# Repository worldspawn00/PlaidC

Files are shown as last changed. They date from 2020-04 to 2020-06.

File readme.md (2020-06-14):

# Plaid type C

Plaid C

Redesign of the Plaid PCB to use USBC and 2u stabilized layouts

Assembly and BOM generally follows the standard Plaid with the exception of the USBC port (USB4085-GF-A GCT) and 2 additional 5.1k resistors for C to C identification.  The PCB can also now take PCB-mount 2u stabilizers for the 2u spacebar locations, clip in or screw in will work.

https://github.com/hsgw/plaid/blob/master/doc/en/soldering.md

* Keyboard Maintainer: [Worldspawn00](https://github.com/Worldspawn00)

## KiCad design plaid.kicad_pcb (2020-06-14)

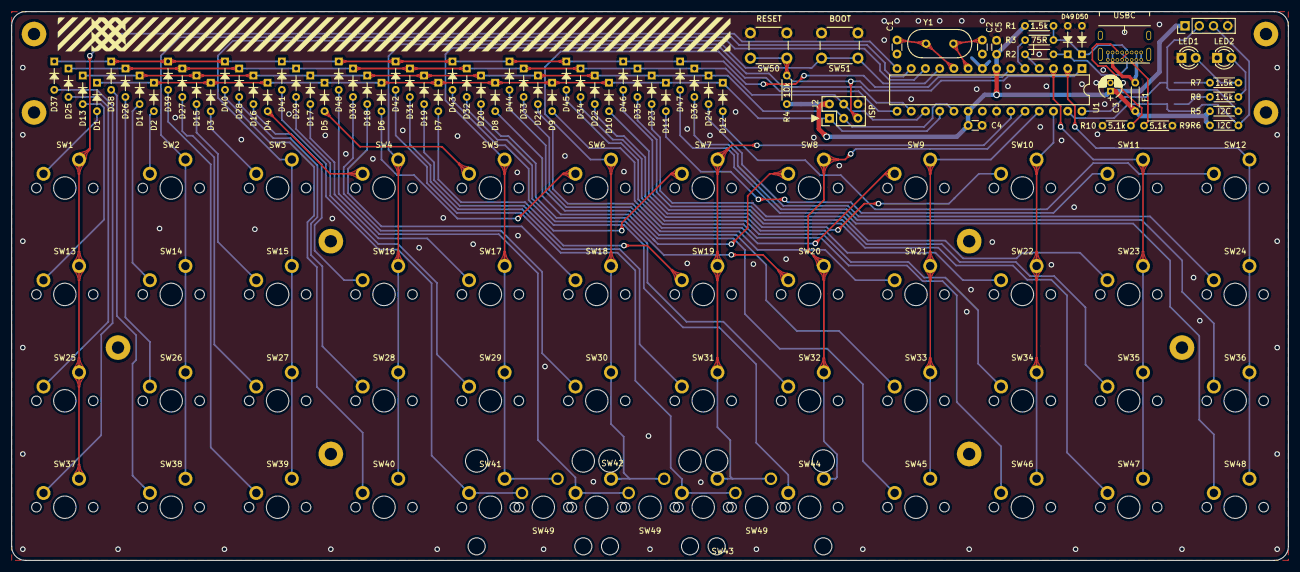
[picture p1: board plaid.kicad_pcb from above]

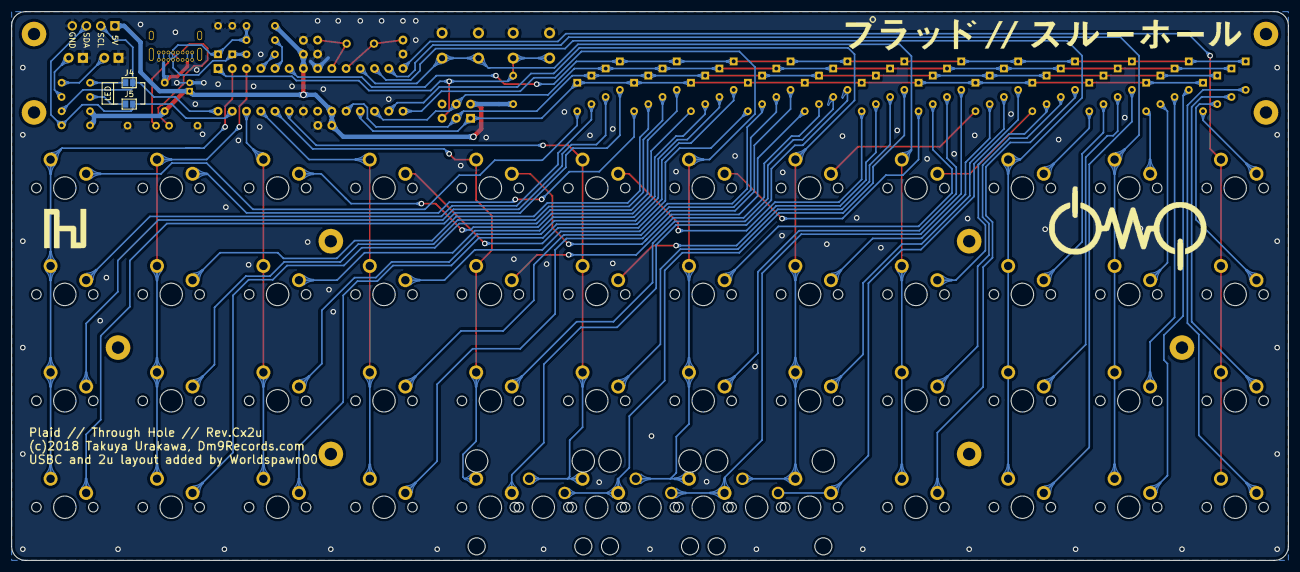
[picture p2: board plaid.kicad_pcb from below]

Board: 2 copper layers, 228.0 x 98.0 mm, 138 parts (2 on the bottom side), 80 nets.

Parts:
C1, C2: 20p; C_Disc_D3.0mm_W1.6mm_P2.50mm
C3: 4.7u; CP_Radial_D4.0mm_P1.50mm
C4, C5: 100n; C_Disc_D3.0mm_W1.6mm_P2.50mm
D1, D2, D3, D4, D5, D6, D7, D8, D9, D10, D11, D12, D13, D14, D15, D16, D17, D18, D19, D20, D21, D22, D23, D24, D25, D26, D27, D28, D29, D30, D31, D32, D33, D34, D35, D36, D37, D38, D39, D40, D41, D42, D43, D44, D45, D46, D47, D48: 1N4148; D_DO-35_SOD27_P5.08mm_Horizontal
D49, D50: 3.6V; D_DO-35_SOD27_P5.08mm_Horizontal
F1: 250mA; polyfuse_5.1mm
H1, H2, H3, H4, H5, H6, H7, H8, H9, H10: M2; MountingHole_2.2mm_M2_Pad
J2: AVR_ISP_6; Pin_Header_Straight_2x03_Pitch2.54mm
J3: Conn_01x04; Pin_Header_Straight_1x04_Pitch2.54mm
J4, J5: GS2
LED1: RED; LED_D3.0mm
LED2: GREEN; LED_D3.0mm
R1, R7, R8: 1.5k; R_Axial_DIN0204_L3.6mm_D1.6mm_P5.08mm_Horizontal
R2: 68R; R_Axial_DIN0204_L3.6mm_D1.6mm_P5.08mm_Horizontal
R3: 75R; R_Axial_DIN0204_L3.6mm_D1.6mm_P5.08mm_Horizontal
R4: 10k; R_Axial_DIN0204_L3.6mm_D1.6mm_P5.08mm_Horizontal
R5, R6: I2C; R_Axial_DIN0204_L3.6mm_D1.6mm_P5.08mm_Horizontal
R9, R10: 5.1k; R_Axial_DIN0204_L3.6mm_D1.6mm_P5.08mm_Horizontal
SW1, SW2, SW3, SW4, SW5, SW6, SW7, SW8, SW9, SW10, SW11, SW12, SW13, SW14, SW15, SW16, SW17, SW18, SW19, SW20, SW21, SW22, SW23, SW24, SW25, SW26, SW27, SW28, SW29, SW30, SW31, SW32, SW33, SW34, SW35, SW36, SW37, SW38, SW39, SW40, SW41, SW42, SW43, SW44, SW45, SW46, SW47, SW48: SW_Push; SW_Cherry_MX1A_1.00u_PCB
SW49, SW49#2, SW49#3: SW_Push; MXOnly-2U-ReversedStabilizers-NoLED
SW50: RESET; SW_PUSH_6mm
SW51: BOOT; SW_PUSH_6mm
U1: ATMEGA328-PU; DIP-28_W7.62mm
USBC: USB_C_USB4085; USB_C_GCT_USB4085
Y1: 16MHz; Crystal_HC49-4H_Vertical

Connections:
+5V: C3.1, C4.1, C5.1, F1.2, J2.2, J3.1, R1.2, R4.1, R5.1, R6.1, U1.7, U1.20
/COL0: SW1.2, SW13.2, SW25.2, SW37.2, U1.14
/COL1: SW2.2, SW14.2, SW26.2, SW38.2, U1.13
/COL2: SW3.2, SW15.2, SW27.2, SW39.2, U1.12
/COL3: SW4.2, SW16.2, SW28.2, SW40.2, SW51.1, U1.11
/COL4: SW5.2, SW17.2, SW29.2, SW41.2, SW49#2.2, U1.16
/COL5: SW6.2, SW18.2, SW30.2, SW42.2, SW49#3.2, U1.15
/COL6: SW7.2, SW19.2, SW31.2, SW43.2, SW49.2, U1.23
/COL7: SW8.2, SW20.2, SW32.2, SW44.2, U1.24
/COL8: SW9.2, SW21.2, SW33.2, SW45.2, U1.25
/COL9: SW10.2, SW22.2, SW34.2, SW46.2, U1.26
/COL10: SW11.2, SW23.2, SW35.2, SW47.2, U1.3
/COL11: SW12.2, SW24.2, SW36.2, SW48.2, U1.2
/RESET: J2.5, R4.2, SW50.1, U1.1
/ROW0: D1.1, D2.1, D3.1, D4.1, D5.1, D6.1, D7.1, D8.1, D9.1, D10.1, D11.1, D12.1, J2.1, U1.18
/ROW1: D13.1, D14.1, D15.1, D16.1, D17.1, D18.1, D19.1, D20.1, D21.1, D22.1, D23.1, D24.1, J2.3, U1.19
/ROW2: D25.1, D26.1, D27.1, D28.1, D29.1, D30.1, D31.1, D32.1, D33.1, D34.1, D35.1, D36.1, J2.4, U1.17
/ROW3: D37.1, D38.1, D39.1, D40.1, D41.1, D42.1, D43.1, D44.1, D45.1, D46.1, D47.1, D48.1, U1.6
/USB_D+: R2.1, U1.4
/USB_D-: R3.1, U1.5
/i2c_SCL: J3.2, J4.2, R5.2, U1.28
/i2c_SDA: J3.3, J5.2, R6.2, U1.27
GND: C1.2, C2.2, C3.2, C4.2, C5.2, D49.2, D50.2, J2.6, J3.4, LED1.1, LED2.1, R9.1, R10.1, SW50.2, SW51.2, U1.8, U1.22, USBC.A1, USBC.A12, USBC.B1, USBC.B12
unnamed: C1.1, U1.10, Y1.2
unnamed: C2.1, U1.9, Y1.1
unnamed: D1.2, SW1.1
unnamed: D2.2, SW2.1
unnamed: D3.2, SW3.1
unnamed: D4.2, SW4.1
unnamed: D5.2, SW5.1
unnamed: D6.2, SW6.1
unnamed: D7.2, SW7.1
unnamed: D8.2, SW8.1
unnamed: D9.2, SW9.1
unnamed: D10.2, SW10.1
unnamed: D11.2, SW11.1
unnamed: D12.2, SW12.1
unnamed: D13.2, SW13.1
unnamed: D14.2, SW14.1
unnamed: D15.2, SW15.1
unnamed: D16.2, SW16.1
unnamed: D17.2, SW17.1
unnamed: D18.2, SW18.1
unnamed: D19.2, SW19.1
unnamed: D20.2, SW20.1
unnamed: D21.2, SW21.1
unnamed: D22.2, SW22.1
unnamed: D23.2, SW23.1
unnamed: D24.2, SW24.1
unnamed: D25.2, SW25.1
unnamed: D26.2, SW26.1
unnamed: D27.2, SW27.1
unnamed: D28.2, SW28.1
unnamed: D29.2, SW29.1
unnamed: D30.2, SW30.1
unnamed: D31.2, SW31.1
unnamed: D32.2, SW32.1
unnamed: D33.2, SW33.1
unnamed: D34.2, SW34.1
unnamed: D35.2, SW35.1
unnamed: D36.2, SW36.1
unnamed: D37.2, SW37.1
unnamed: D38.2, SW38.1
unnamed: D39.2, SW39.1
unnamed: D40.2, SW40.1
unnamed: D41.2, SW41.1, SW49#2.1
unnamed: D42.2, SW43.1, SW49.1
unnamed: D43.2, SW44.1
unnamed: D44.2, SW45.1
unnamed: D45.2, SW46.1
unnamed: D46.2, SW47.1
unnamed: D47.2, SW48.1
unnamed: D48.2, SW42.1, SW49#3.1
unnamed: D49.1, R2.2, USBC.A6, USBC.B6
unnamed: D50.1, R1.1, R3.2, USBC.A7, USBC.B7
unnamed: F1.1, USBC.A4, USBC.A9, USBC.B4, USBC.B9
unnamed: J4.1, R7.1
unnamed: J5.1, R8.1
unnamed: LED1.2, R7.2
unnamed: LED2.2, R8.2

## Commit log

2020-05-28 generating gerbers
    [plaid_bottom-B_Cu.gbl, plaid_bottom-B_Mask.gbs, plaid_bottom-B_Paste.gbp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]
2020-06-13 fixing spacebar footprints
    [plaid-B_Cu.gbl, plaid-B_Mask.gbs, plaid-B_Paste.gbp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]
2020-06-14 adding 2x2u layout
    [plaid-B_Cu.gbl, plaid-B_Mask.gbs, plaid-B_Paste.gbp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]
2020-06-14 fix resistor value
    [plaid-B_Cu.gbl, plaid-B_Mask.gbs, plaid-B_Paste.gbp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]

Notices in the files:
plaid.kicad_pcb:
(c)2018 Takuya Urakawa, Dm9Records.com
